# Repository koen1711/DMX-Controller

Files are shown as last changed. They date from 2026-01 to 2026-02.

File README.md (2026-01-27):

# DMX Controller

DMX controller board based on ESP32 NodeMCU. Implementing both plain DMX and RDM while being able to read the entire DMX frame.

## Why?

We have an Theathre stage at school, we do a musical around christmas every year. We wanted to engineer boxes with LED Strips, alarms, etc. 
These things needed to respond with the lighting we already use, so DMX was chosen. Thus I started working on the controllers to control non traditional lights on the stage.

## How?

Now to use the project it's actually pretty simple, you plug in atleast one XLR cable for DMX in the ports, next you wire something up or just use the ESP32 to control DMX.
The possibilities are endless, we engineered it in a way that using a Mesh you can connect more things through one Controller. 

You need the PCB itself, female headers for the ESP32 and the ESP32 itself. Wire up what you need through the GPIO pins.

## Wiring diagram



## Bill of Materials

| Item | Qty. | Price (USD) | Ext. (USD) | Link |
|---|---|---|---|---|
| 470µF 35V Electrolytic Capacitor (C1) | 1 | $0.0576 | $0.06 | [C2836436](https://www.lcsc.com/product-detail/C2836436.html) |
| 100µF 16V Electrolytic Capacitor (C12) | 1 | $0.0101 | $0.01 | [C4747963](https://www.lcsc.com/product-detail/C4747963.html) |
| 180µF 25V Electrolytic Capacitor (C3) | 1 | $0.0240 | $0.02 | [C49233128](https://www.lcsc.com/product-detail/C49233128.html) |
| Schottky Diode 40V 5A SMA (D4) | 1 | $0.0194 | $0.02 | [C22452](https://www.lcsc.com/product-detail/C22452.html) |
| 1x7 Pin Header 2.54mm | 7 | $0.0171 | $0.12 | [C6332200](https://www.lcsc.com/product-detail/C6332200.html) |
| XLR Male Connector - DMX IN (J1) | 1 | $0.3153 | $0.32 | [C309324](https://www.lcsc.com/product-detail/C309324.html) |
| XLR Female Connector - DMX OUT (J2) | 1 | $0.3287 | $0.33 | [C309326](https://www.lcsc.com/product-detail/C309326.html) |
| DC Barrel Jack 2.0mm (J3) | 1 | $0.0296 | $0.03 | [C16214](https://www.lcsc.com/product-detail/C16214.html) |
| 68µH Inductor 0805 (L1) | 1 | $0.0162 | $0.02 | [C275376](https://www.lcsc.com/product-detail/C275376.html) |
| 680Ω 0805 Resistor (R1, R2) | 2 | $0.0017 | $0.00 | [C17798](https://www.lcsc.com/product-detail/C17798.html) |
| 120Ω 0805 Resistor (R3) | 1 | $0.0010 | $0.00 | [C17437](https://www.lcsc.com/product-detail/C17437.html) |
| DPDT Slide Switch (SW1) | 1 | $0.0459 | $0.05 | [C431542](https://www.lcsc.com/product-detail/C431542.html) |
| MAX485 RS-485 Transceiver SO-8 (U1) | 1 | $0.0801 | $0.08 | [C668206](https://www.lcsc.com/product-detail/C668206.html) |
| ESP32 NodeMCU (U3) | 1 | - | - | - |
| XL1509-5.0E1 5V Buck Converter (U4) | 1 | $0.1109 | $0.11 | [C61063](https://www.lcsc.com/product-detail/C61063.html) |
| **Total** | | | **$1.17** | |

*Note: Price excludes U3 (ESP32 NodeMCU) which needs to be sourced separately.*

## Screenshots




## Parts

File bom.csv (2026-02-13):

Designator | Footprint | Quantity | Value | LCSC Part # | Link | Cost
C1 | CP_Elec_6.3x7.7 | 1 | 470u | C2836436
C12 | CP_Elec_6.3x7.7 | 1 | 100u | C4747963
C3 | CP_Elec_6.3x7.7 | 1 | 180u | C49233128
D4 | D_SMA | 1 | D_Schottky | C22452
GND2, GND3, PH2, SCL1, SDA1, VCC2, VCC3 | PinHeader_1x07_P2.54mm_Vertical | 7 | Conn_01x07 | C6332200
J1 | Jack_XLR_Neutrik_NC3MAAH_Horizontal | 1 | DMX_IN | C309324
J2 | Jack_XLR_Neutrik_NC3FAAH-0_Horizontal | 1 | DMX_OUT | C309326
J3 | BarrelJack_Horizontal | 1 | DC-005 2.0 | C16214
L1 | 805 | 1 | 68uL
R1, R2 | 805 | 2 | 680R | C17437
R3 | 805 | 1 | 120R | C17437
SW1 | SW-TH_MSS22D18GX | 1 | POWER_EN | C431542
U1 | SO08 | 1 | MAX3430ESA | C668206
U3 | MODULE_ESP32_NODEMCU | 1 | ESP32_NODEMCU
U4 | 5V_BUCK | 1 | XL1509-5.0E1 | C61063
LEDStrip | N/A | 1 |  |  | https://nl.aliexpress.com/item/1005005571899461.html?curPageLogUid=jPtSYklllg8A | €13.59
Cover 1m | N/A | 2 |  |  | https://acrylhaus.com/Acrylglasrohr-rund-XT-satiniert-O-20-14mm-Aussen-Innen-1000mm | €38.86
PCB | N/A | 5 |  |  | N/A | €1.74
PCBA | N/A | 5 |  |  | N/A | €34.24

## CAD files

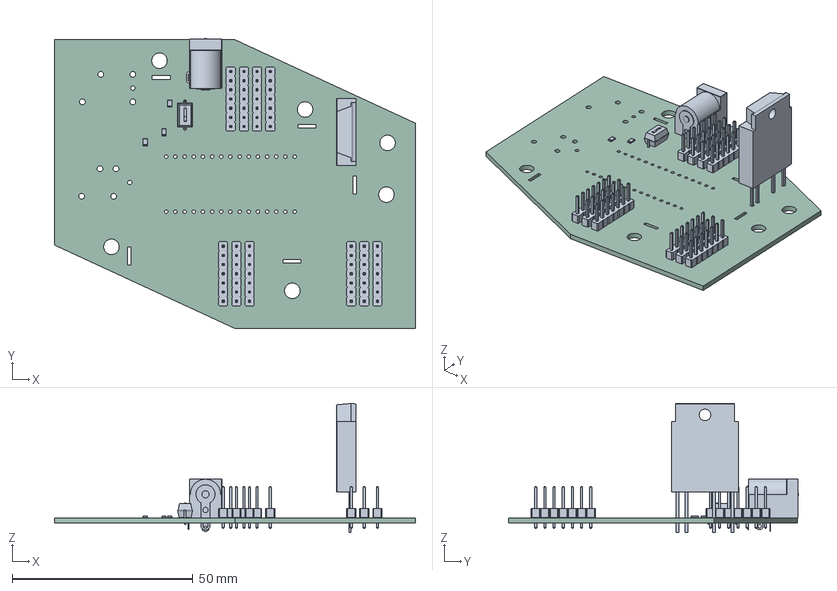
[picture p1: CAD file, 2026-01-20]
DMX-Controller.step
100.0 x 80.4 x 35.8 mm
PinHeader_1x07_P2.54mm_Vertical x 10
R_0805_2012Metric x 3
SW_DIP_SPSTx01_Slide_6.7x4.1mm_W7.62mm_P2.54mm_LowProfile
BarrelJack_Horizontal
SIP4_Sharp-SSR_P7.62mm_Straight
DMX-Controller_PCB

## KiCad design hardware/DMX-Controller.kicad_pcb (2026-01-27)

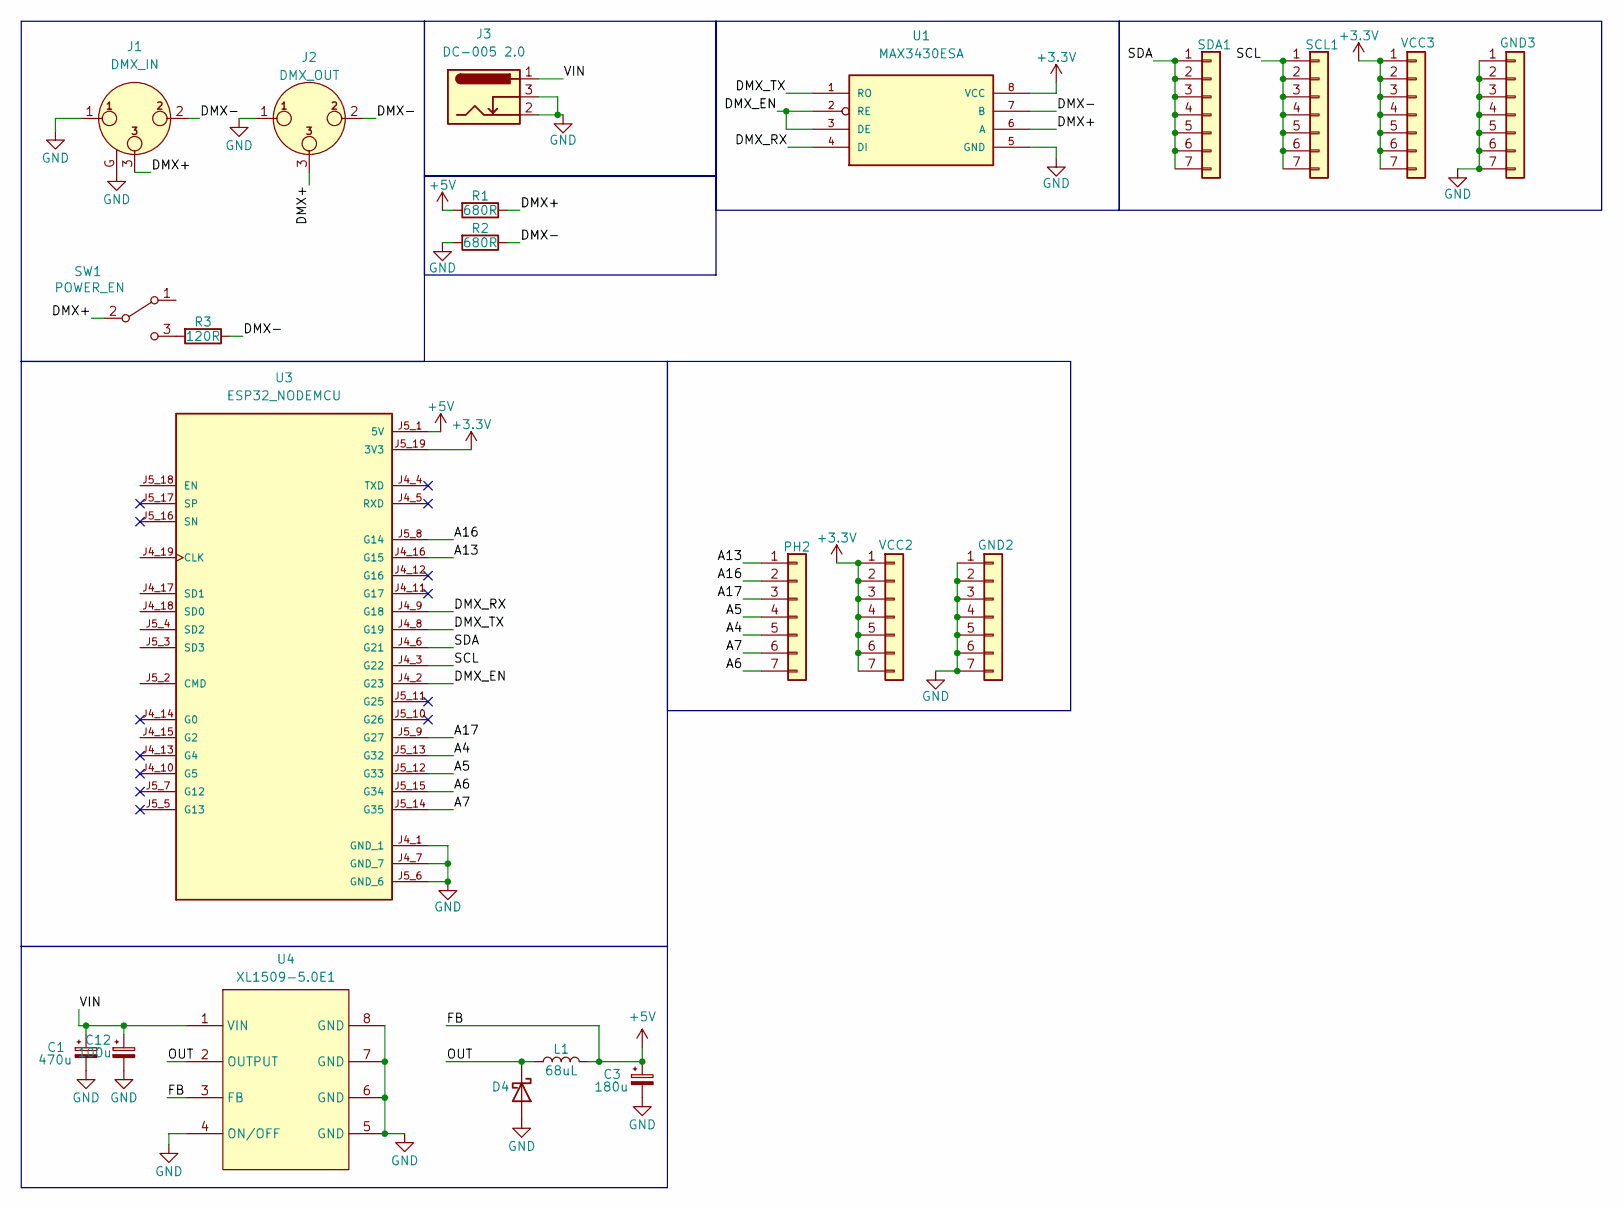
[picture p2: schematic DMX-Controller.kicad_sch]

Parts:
C1: 470u; CP_Elec_6.3x7.7; MPN C2836436
C3: 180u; CP_Elec_6.3x7.7; MPN C49233128
C12: 100u; CP_Elec_6.3x7.7; MPN C4747963
D4: D_Schottky; D_SMA; MPN C22452
GND2, GND3: Conn_01x07; PinHeader_1x07_P2.54mm_Vertical; MPN C6332200
J1: DMX_IN; Jack_XLR_Neutrik_NC3MAAH_Horizontal; MPN C309324
J2: DMX_OUT; Jack_XLR_Neutrik_NC3FAAH-0_Horizontal; MPN C309326
J3: DC-005 2.0; BarrelJack_Horizontal; MPN C16214
L1: 68uL; L_0805_2012Metric
PH2: Conn_01x07; PinHeader_1x07_P2.54mm_Vertical; MPN C6332200
R1, R2: 680R; R_0805_2012Metric; MPN C17437
R3: 120R; R_0805_2012Metric; MPN C17437
SCL1: Conn_01x07; PinHeader_1x07_P2.54mm_Vertical; MPN C6332200
SDA1: Conn_01x07; PinHeader_1x07_P2.54mm_Vertical; MPN C6332200
SW1: POWER_EN; SW-TH_MSS22D18GX; MPN C431542
U1: MAX3430ESA; SO08; MPN C668206
U3: ESP32_NODEMCU; MODULE_ESP32_NODEMCU
U4: XL1509-5.0E1; 5V_BUCK; MPN C61063
VCC2, VCC3: Conn_01x07; PinHeader_1x07_P2.54mm_Vertical; MPN C6332200

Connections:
+3.3V: U1.8 (VCC), U3.J5_19 (3V3), VCC2.1, VCC2.2, VCC2.3, VCC2.4, VCC2.5, VCC2.6, VCC2.7, VCC3.1, VCC3.2, VCC3.3, VCC3.4, VCC3.5, VCC3.6, VCC3.7
+5V: C3.1, L1.2, R1.2, U3.J5_1 (5V), U4.3 (FB)
/A4: PH2.5, U3.J5_13 (G32)
/A5: PH2.4, U3.J5_12 (G33)
/A6: PH2.7, U3.J5_15 (G34)
/A7: PH2.6, U3.J5_14 (G35)
/A13: PH2.1, U3.J4_16 (G15)
/A16: PH2.2, U3.J5_8 (G14)
/A17: PH2.3, U3.J5_9 (G27)
/DMX+: J1.3, J2.3, R1.1, SW1.2 (B), U1.6 (A)
/DMX-: J1.2, J2.2, R2.1, R3.1, U1.7 (B)
/DMX_EN: U1.2 (RE), U1.3 (DE), U3.J4_2 (G23)
/DMX_RX: U1.4 (DI), U3.J4_9 (G18)
/DMX_TX: U1.1 (RO), U3.J4_8 (G19)
/OUT: D4.1 (K), L1.1, U4.2 (OUTPUT)
/SCL: SCL1.1, SCL1.2, SCL1.3, SCL1.4, SCL1.5, SCL1.6, SCL1.7, U3.J4_3 (G22)
/SDA: SDA1.1, SDA1.2, SDA1.3, SDA1.4, SDA1.5, SDA1.6, SDA1.7, U3.J4_6 (G21)
/VIN: C1.1, C12.1, J3.1, U4.1 (VIN)
GND: C1.2, C3.2, C12.2, D4.2 (A), GND2.1, GND2.2, GND2.3, GND2.4, GND2.5, GND2.6, GND2.7, GND3.1, GND3.2, GND3.3, GND3.4, GND3.5, GND3.6, GND3.7, J1.1, J1.G, J2.1, J3.2, J3.3, R2.2, U1.5 (GND), U3.J4_1 (GND_1), U3.J4_7 (GND_7), U3.J5_6 (GND_6), U4.4 (ON/OFF), U4.5 (GND), U4.6 (GND), U4.7 (GND), U4.8 (GND)
unnamed: R3.2, SW1.3 (C)

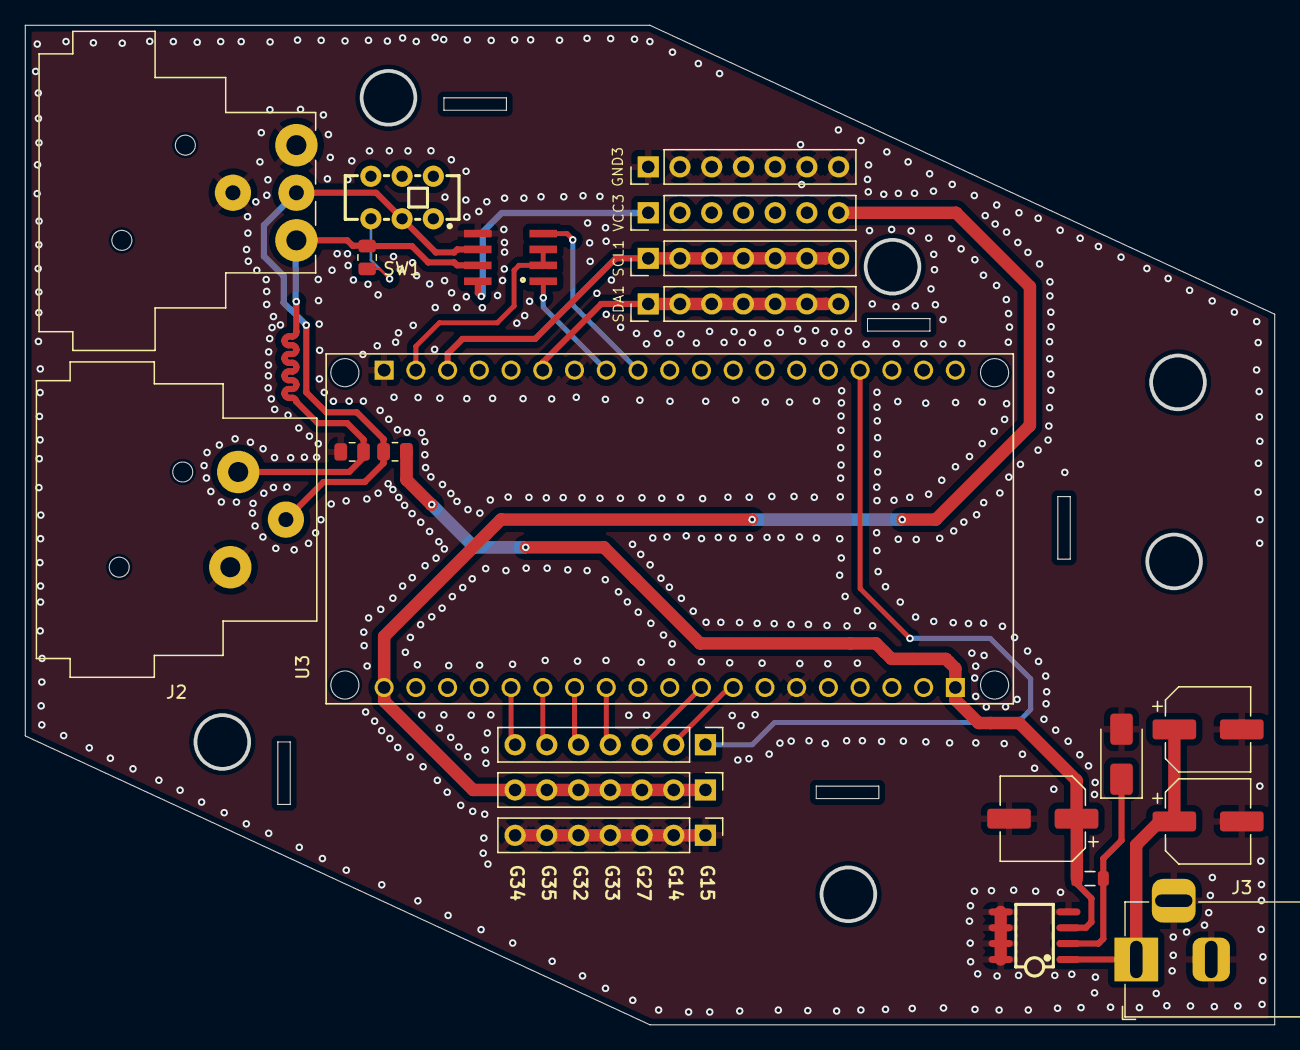
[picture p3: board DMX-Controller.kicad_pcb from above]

Board: 2 copper layers, 100.0 x 80.0 mm, 22 parts (0 on the bottom side), 20 nets.

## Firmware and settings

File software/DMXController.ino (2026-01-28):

#include <Arduino.h>
#include <esp_dmx.h>

int transmitPin = 18;
int receivePin = 19;
int enablePin = 23;

dmx_port_t dmxPort = 1;
byte data[DMX_PACKET_SIZE];

bool dmxIsConnected = false;

void setup() {
  Serial.begin(115200);

  dmx_config_t config = DMX_CONFIG_DEFAULT;
  dmx_personality_t personalities[] = {
    {1, "Default Personality"}
  };
  int personality_count = 1;
  dmx_driver_install(dmxPort, &config, personalities, personality_count);
  dmx_set_pin(dmxPort, transmitPin, receivePin, enablePin);
}

void loop() {
  dmx_packet_t packet;
  if (dmx_receive(dmxPort, &packet, DMX_TIMEOUT_TICK)) {
    if (!packet.err) {
      if (!dmxIsConnected) {
        Serial.println("DMX is connected!");
        dmxIsConnected = true;
      }
      dmx_read(dmxPort, data, packet.size);

      // Read channel 0
      if (data[0] > 0) {
        // DO SOMETHING WITH VALUE
      }

    } else {
      Serial.println("A DMX error occurred.");
    }
  }
}

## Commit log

2026-01-20 chore: final version of PCB
    [DMX-Controller.kicad_pcb, DMX-Controller.kicad_sch, DMX-Controller.step]
2026-01-27 chore: add BOM to README.md
2026-01-27 Update README with project details and BOM
    Expanded project description and added context about the DMX controller's purpose for school theatre productions.
2026-01-27 chore: fix 3d model
    [DMX-Controller.kicad_pcb, DMX-Controller.kicad_sch]
2026-01-27 chore: sort files
    [DMX-Controller.kicad_pcb, DMX-Controller.kicad_sch]
2026-02-13 chore: update BOM
    [bom.csv]
